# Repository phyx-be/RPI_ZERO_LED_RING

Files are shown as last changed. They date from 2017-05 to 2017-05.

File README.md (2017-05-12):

# RPI_ZERO_LED_RING

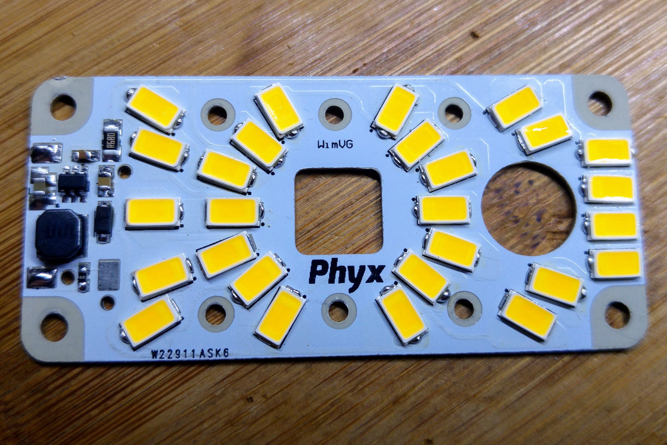
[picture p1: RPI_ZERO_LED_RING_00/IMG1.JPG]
RPI_ZERO_LED_RING_00_IMG1


A metal core LED ring that fits the RPi Zero and Rpi Camera. By adding a heatsink or metal plate to the back, this board can run continuously at full power. (which is not possible with the [RPI_HAT_FLASH](http://phyx.be/RPI_HAT_FLASH))

## Hardware Revision 00

The board has been designed around the [Ti TPS61165](http://www.ti.com/product/TPS61165) wide input white LED driver. It has an optional PWM input allowing the RPI to control the brightness of the LEDs. The round hole in the board will fit a [Panasonic EKMC1601113 PIR](http://na.industrial.panasonic.com/products/sensors/sensors-automotive-industrial-applications/pir-motion-sensor-papirs/series/vz-series/2481) which can come in handy to enable or disable the LEDs based on movement detection.

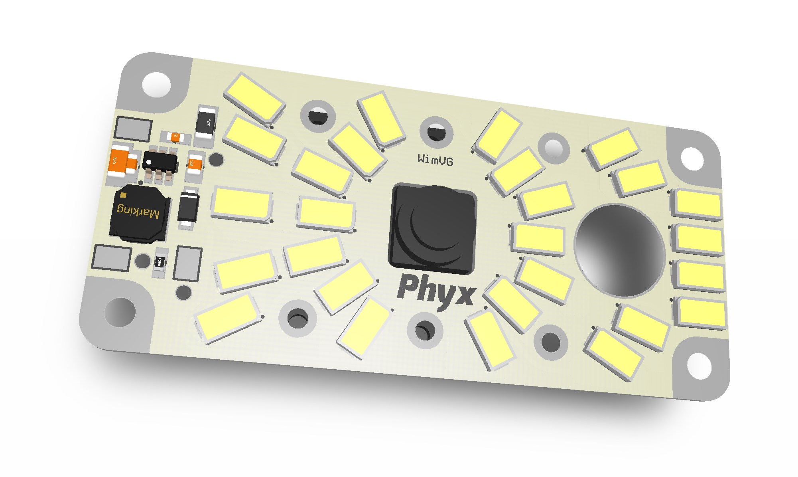
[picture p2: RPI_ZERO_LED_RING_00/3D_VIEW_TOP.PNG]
RPI_ZERO_LED_RING_00_TOP

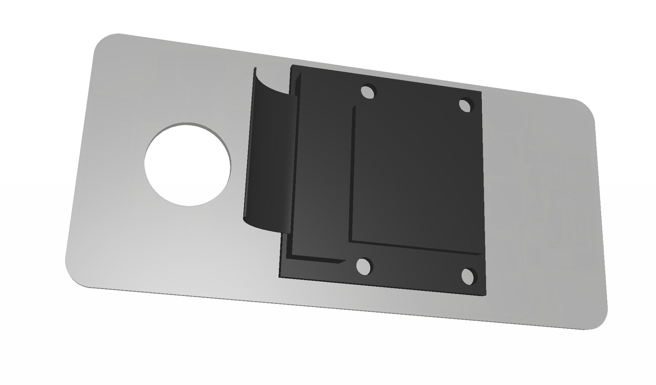
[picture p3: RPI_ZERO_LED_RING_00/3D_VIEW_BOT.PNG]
RPI_ZERO_LED_RING_00_BOT


### Known issues

* No markings near power and PWM pads
* Screw holes aren't perfectly aligned for the camera
* Will only work with voltages higher than 8V, optimal 12V

## Pictures

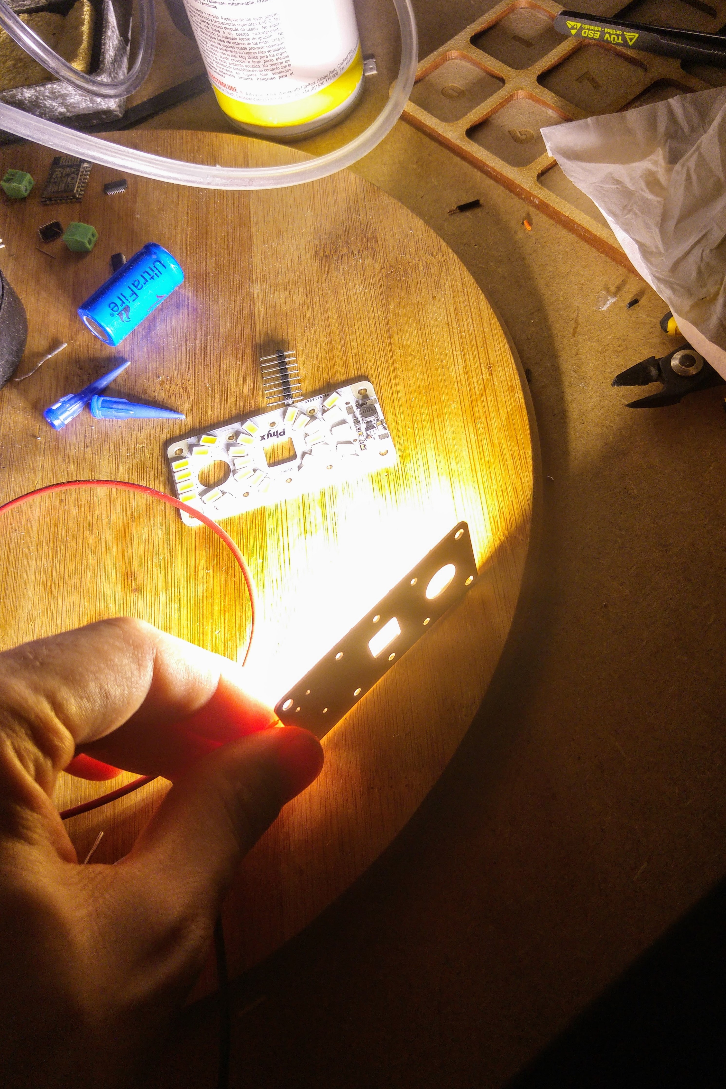
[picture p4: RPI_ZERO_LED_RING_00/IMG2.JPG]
RPI_ZERO_LED_RING_00_IMG2

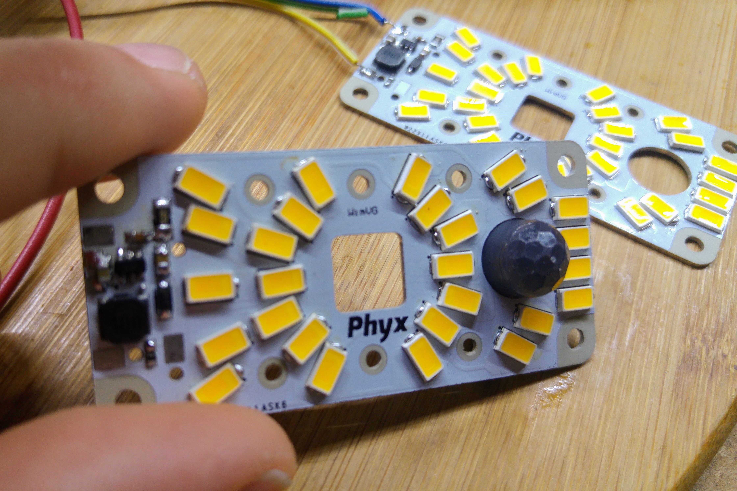
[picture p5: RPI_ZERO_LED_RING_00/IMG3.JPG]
RPI_ZERO_LED_RING_00_IMG3


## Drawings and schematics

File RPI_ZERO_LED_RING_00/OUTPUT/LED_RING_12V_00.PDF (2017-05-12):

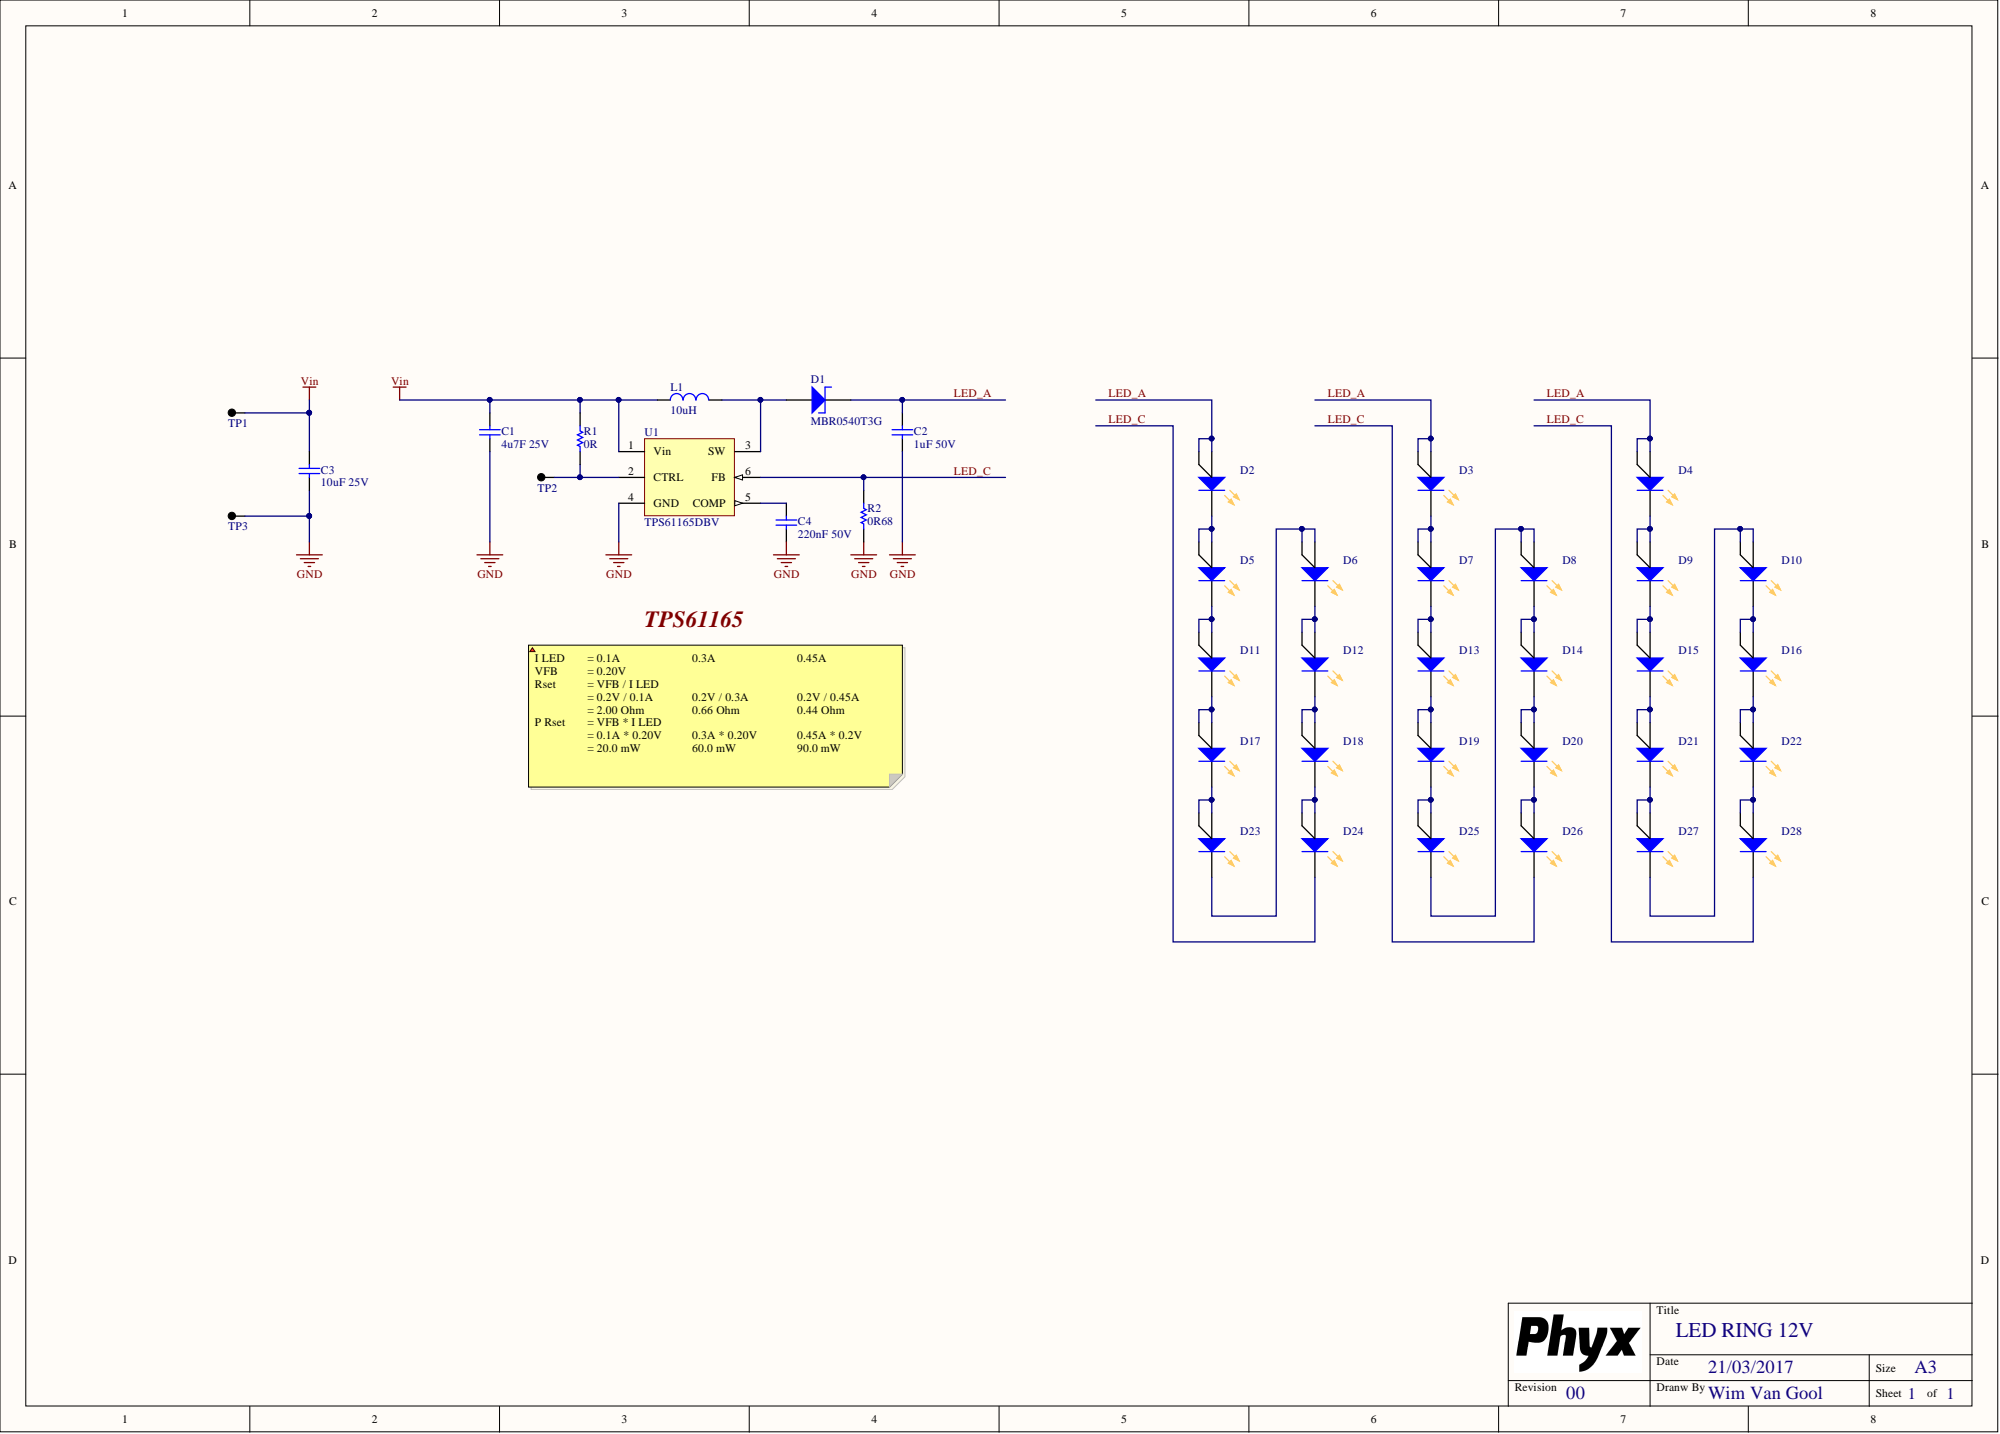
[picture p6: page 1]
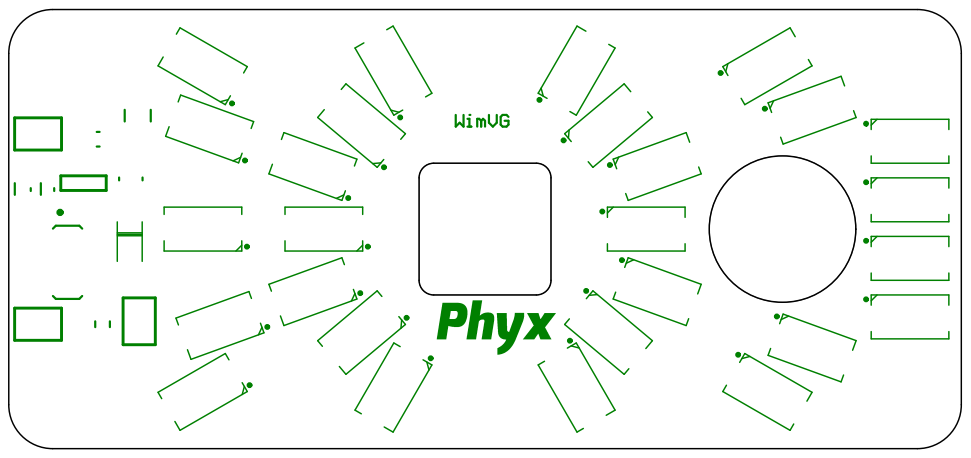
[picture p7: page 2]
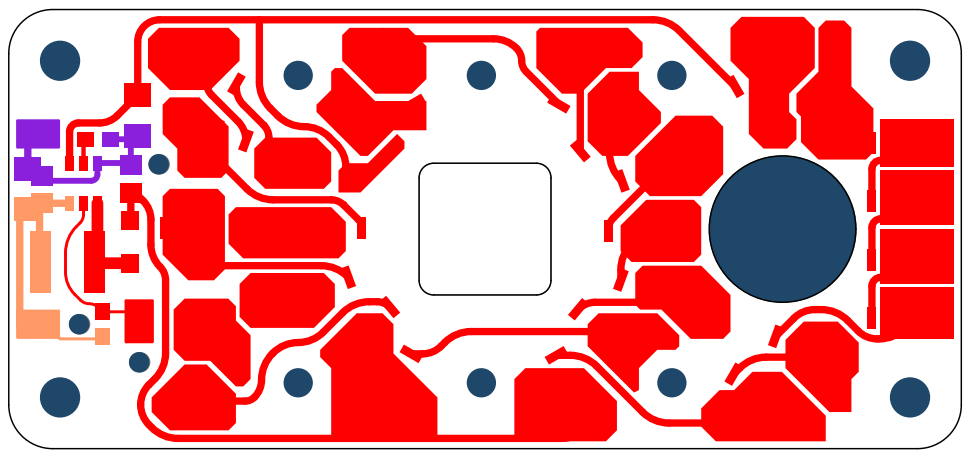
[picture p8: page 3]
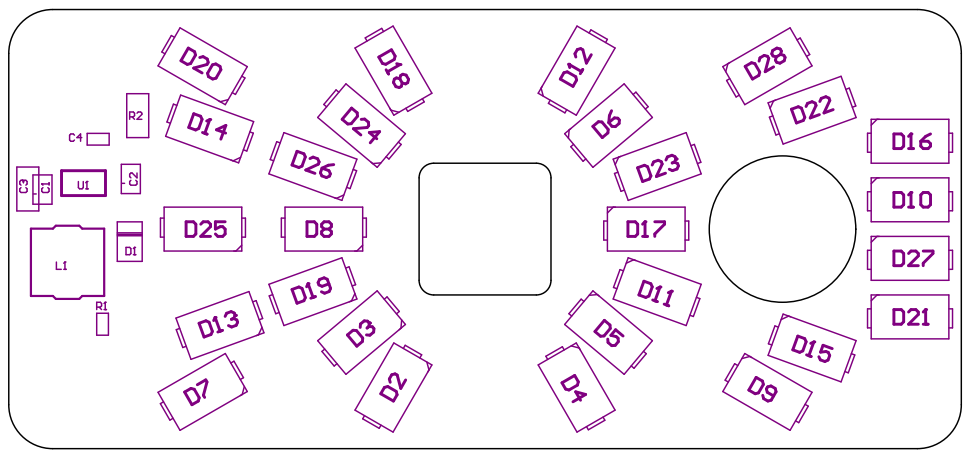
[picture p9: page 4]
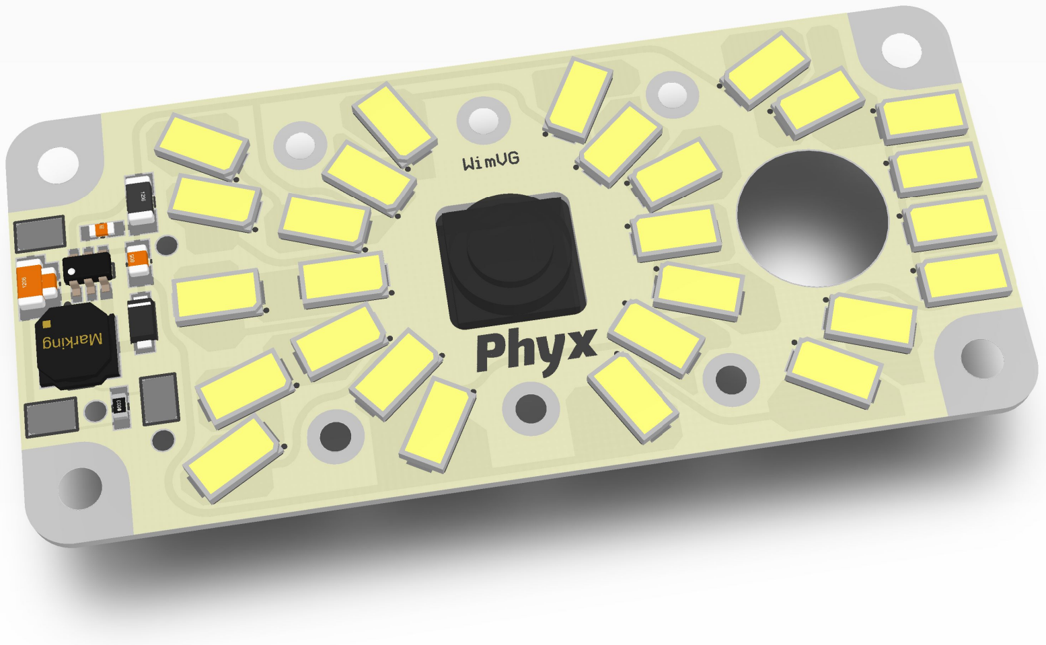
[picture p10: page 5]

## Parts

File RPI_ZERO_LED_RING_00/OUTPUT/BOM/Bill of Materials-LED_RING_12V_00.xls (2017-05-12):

Bill of Materials |  |  | HAT_FLASH
Project: |  | LED_RING_12V_00.PrjPcb
Revision: |  | 00
Variant: |  | None
Creation Date: | 23/03/2017 | 8:07:39
Print Date: | 2017-03-27 | 11:10:03
Footprint | Comment | LibRef | Designator | Value | Description | Supplier 1 | Supplier Part Number 1 | Quantity
C0805_N |  | CAP # 4u7F 25V 0805 | C1 | 4u7F 25V | Capacitor Ceramic | Farnell | 2362111 | 1
C0805_N |  | CAP # 1uF 50V 0805 | C2 | 1uF 50V | Capacitor Ceramic | Farnell | 1845750 | 1
C1206_N |  | CAP # 10uF 25V 1206 | C3 | 10uF 25V | Capacitor Ceramic | Farnell | 2320887 | 1
C0603_N |  | CAP # 220nF 50V 0603 | C4 | 220nF 50V | Capacitor Ceramic | Farnell | 2346906 | 1
ON_SOD-123FL | MBR0540T3G Schottky ULTRAFAST, 500MA, 40V | Schottky # MBR0540T3G | D1 | MBR0540T3G |  | Farnell | 2101839 | 1
LED_LM561A | 5630 5630AZLxx Lite ON LED | LED # LiteOn LTW-5630AZL27 | D2, D3, D4, D5, D6, D7, D8, D9, D10, D11, D12, D13, D14, D15, D16, D17, D18, D19, D20, D21, D22, D23, D24, D25, D26, D27, D28 | LTW-5630AZL27 |  | Digikey | 160-2091-1-ND | 27
LAIRD_TYS5020 | TYS5020100M-10 | IND # 10uH TYS5020100M-10 | L1 | 10uH |  | Farnell | 2292527 | 1
R0603_N |  | RES # 0R 0603 | R1 | 0R |  | Farnell | 2447743 | 1
R1206 |  | RES # 0R68 1206 | R2 | 0R68 |  | Farnell | 2008307 | 1
TP_2x3mm |  | TP # 2x3mm | TP1, TP2, TP3 | NO BOM |  |  |  | 3
TI_DBV_R-PDSO-G6 | TPS61165 38-V Boost WLED Driver with PWM | LED_DRVR # TPS61165 | U1 | TPS61165DBV |  | Farnell | 2323441 | 1
 |  |  |  |  |  |  |  | 39
Approved |  | Notes
